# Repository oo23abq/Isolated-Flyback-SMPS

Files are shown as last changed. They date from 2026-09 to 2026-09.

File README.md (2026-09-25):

# Isolated-Flyback-SMPS-Project-
A breakdown of my first independent PCB project, which was the design of a DC-DC  switch-mode power supply (SMPS) in the flyback converter topology.

## Repository Structure

```markdown

```text
├── docs/                                       # General Documentation 
│   └── report.md                               # Lab Test Report
├── gerbers/                                    # Manufacturing Files
│   └── flybackgerbers.zip                      # Gerber and Drill Archives
├── images/                                     # 3D Renders 
│   ├── lt8300flyback_bottom.png                # Bottom Layer 
│   └── lt8300flyback_top.png                   # Top Layer
├── kicad/                                      # KiCAD Project Files 
│   ├── LT8300_Flyback_RevA.kicad_pcb           # PCB Board File
│   ├── LT8300_Flyback_RevA.kicad_sch           # Schematic File
│   └── LT8300flyback_bom.csv                   # Bill of Materials
├── ltspice/                                    # Analogue Simulation 
│   └── waveform.png                            # LTspice Transient Simulation 
├── testing/                                    # Lab Testing
│   ├── oscilloscopeinput.png                   # Input Voltage (P-Coil)
│   ├── oscilloscopeoutput.png                  # Output Voltage (S-Coil)
│   └── testsetup.png                           # Bench Test Setup 
├── LICENSE                                     # License file
└── README.md                                   # Project documentation and summary

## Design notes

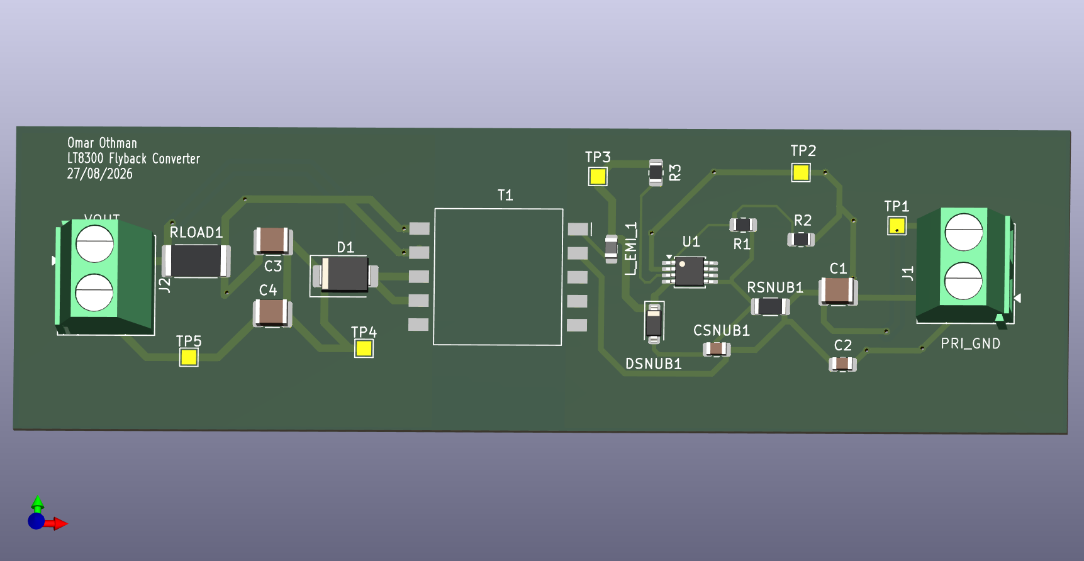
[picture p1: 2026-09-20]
images/lt8300flyback_top.png

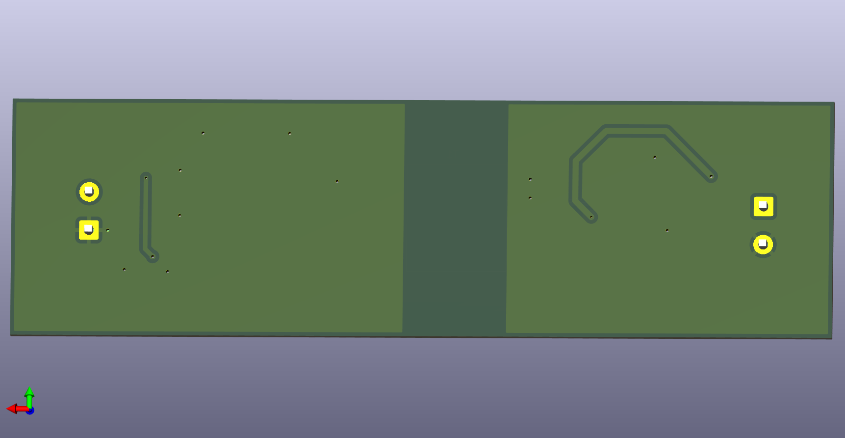
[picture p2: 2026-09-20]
images/lt8300flyback_bottom.png

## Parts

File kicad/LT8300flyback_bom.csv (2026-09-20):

Reference | Qty | Value | DNP | Exclude from BOM | Exclude from Board | Footprint | Datasheet
C1 | 1 | 47u |  |  |  | Capacitor_SMD:C_1210_3225Metric | ~
C2 | 1 | 47n |  |  |  | Capacitor_SMD:C_0805_2012Metric | ~
C3,C4 | 2 | 47µ |  |  |  | Capacitor_SMD:C_1210_3225Metric
CSNUB1 | 1 | 0.001µ |  |  |  | Capacitor_SMD:C_0805_2012Metric
D1 | 1 | MBRS1100 |  |  |  | Diode_SMD:D_SMB
DSNUB1 | 1 | 1N4148 |  |  |  | Diode_SMD:D_SOD-123
J1 | 1 | Input |  |  |  | TerminalBlock_Phoenix:TerminalBlock_Phoenix_MKDS-1,5-2-5.08_1x02_P5.08mm_Horizontal | ~
J2 | 1 | Output |  |  |  | TerminalBlock_Phoenix:TerminalBlock_Phoenix_MKDS-1,5-2-5.08_1x02_P5.08mm_Horizontal | ~
L_EMI_1 | 1 | 5n |  |  |  | Inductor_SMD:L_0805_2012Metric | ~
R1,R3 | 2 | 1M |  |  |  | Resistor_SMD:R_0805_2012Metric
R2 | 1 | 40.2K |  |  |  | Resistor_SMD:R_0805_2012Metric
RLOAD1 | 1 | 16 |  |  |  | Resistor_SMD:R_2512_6332Metric
RSNUB1 | 1 | 10K |  |  |  | Resistor_SMD:R_1206_3216Metric
T1 | 1 | EPQ13_6389_10PINS_750318525 |  |  |  | Transformer_SMD_Wurth:T_Wurth_WE-FLYTI-EPQ13_6389_10PINS | https://www.we-online.com/catalog/datasheet/750318525.pdf?ki
TP1 | 1 | TP_VIN |  |  |  | TestPoint:TestPoint_Pad_1.5x1.5mm | ~
TP2 | 1 | TP_PRI_GND |  |  |  | TestPoint:TestPoint_Pad_1.5x1.5mm | ~
TP3 | 1 | TP_SW |  |  |  | TestPoint:TestPoint_Pad_1.5x1.5mm | ~
TP4 | 1 | TP_VOUT+ |  |  |  | TestPoint:TestPoint_Pad_1.5x1.5mm | ~
TP5 | 1 | TP_VOUT- |  |  |  | TestPoint:TestPoint_Pad_1.5x1.5mm | ~
U1 | 1 | LT8300 |  |  |  | Package_SO:MSOP-8-1EP_3x3mm_P0.65mm_EP1.5x1.8mm

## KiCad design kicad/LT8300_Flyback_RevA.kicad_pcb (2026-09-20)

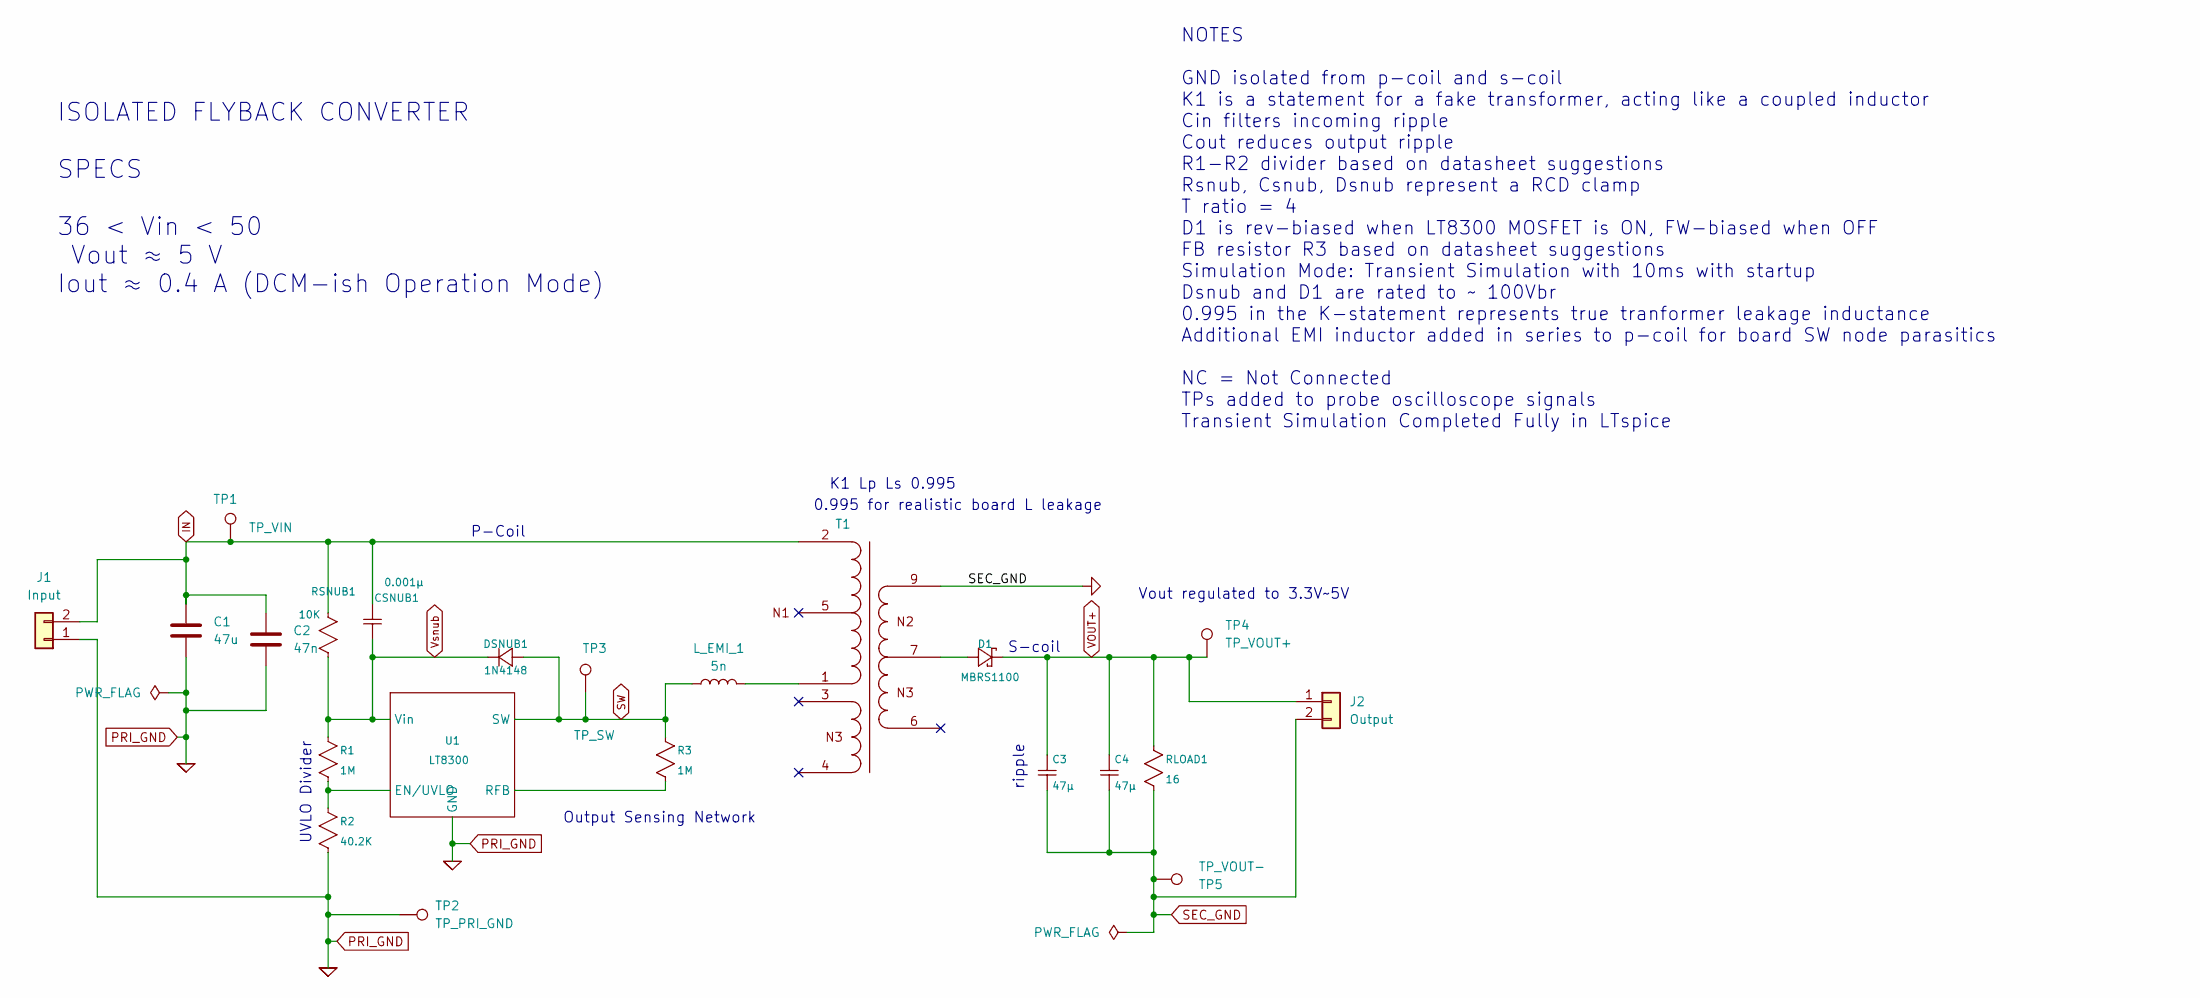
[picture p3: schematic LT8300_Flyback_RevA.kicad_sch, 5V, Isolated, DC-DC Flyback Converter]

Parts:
C1: 47u; C_1210_3225Metric
C2: 47n; C_0805_2012Metric
C3, C4: 47µ; C_1210_3225Metric
CSNUB1: 0.001µ; C_0805_2012Metric
D1: MBRS1100; D_SMB
DSNUB1: 1N4148; D_SOD-123
J1: Input; TerminalBlock_Phoenix_MKDS-1,5-2-5.08_1x02_P5.08mm_Horizont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
J2: Output; TerminalBlock_Phoenix_MKDS-1,5-2-5.08_1x02_P5.08mm_Horizont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
L_EMI_1: 5n; L_0805_2012Metric
R1, R3: 1M; R_0805_2012Metric
R2: 40.2K; R_0805_2012Metric
RLOAD1: 16; R_2512_6332Metric
RSNUB1: 10K; R_1206_3216Metric
T1: EPQ13_6389_10PINS_750318525; T_Wurth_WE-FLYTI-EPQ13_6389_10PINS; Part Number 750318525
TP1: TP_VIN; TestPoint_Pad_1.5x1.5mm
TP2: TP_PRI_GND; TestPoint_Pad_1.5x1.5mm
TP3: TP_SW; TestPoint_Pad_1.5x1.5mm
TP4: TP_VOUT+; TestPoint_Pad_1.5x1.5mm
TP5: TP_VOUT-; TestPoint_Pad_1.5x1.5mm
U1: LT8300; MSOP-8-1EP_3x3mm_P0.65mm_EP1.5x1.8mm

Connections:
IN: C1.1, C2.1, CSNUB1.2, J1.2, RSNUB1.2, T1.2, TP1.1
unnamed: D1.2 (+), T1.7, T1.8
unnamed: L_EMI_1.2, T1.1
unnamed: R1.2, R2.1, U1.1 (EN/UVLO)
unnamed: R3.2, U1.3 (RFB)
PRI_GND: C1.2, C2.2, J1.1, R2.2, TP2.1, U1.2 (GND)
SEC_GND: C3.2, C4.2, J2.2, RLOAD1.2, T1.9, T1.10, TP5.1
SW: DSNUB1.1 (+), L_EMI_1.1, R3.1, TP3.1, U1.4 (SW)
VOUT+: C3.1, C4.1, D1.1 (-), J2.1, RLOAD1.1, TP4.1
Vsnub: CSNUB1.1, DSNUB1.2 (-), R1.1, RSNUB1.1, U1.5 (Vin)

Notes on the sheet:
S-coil
K1 Lp Ls 0.995
UVLO Divider
NOTES GND isolated from p-coil and s-coil K1 is a statement for a fake transformer, acting like a coupled inductor Cin filters incoming ripple Cout reduces output ripple R1-R2 divider based on datasheet suggestions Rsnub, Csnub, Dsnub represent a RCD clamp T ratio = 4 D1 is rev-biased when LT8300 M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
P-Coil
ripple
Vout regulated to 3.3V~5V
ISOLATED FLYBACK CONVERTER SPECS 36 < Vin < 50 Vout ≈ 5 V Iout ≈ 0.4 A (DCM-ish Operation Mode)
0.995 for realistic board L leakage
Output Sensing Network

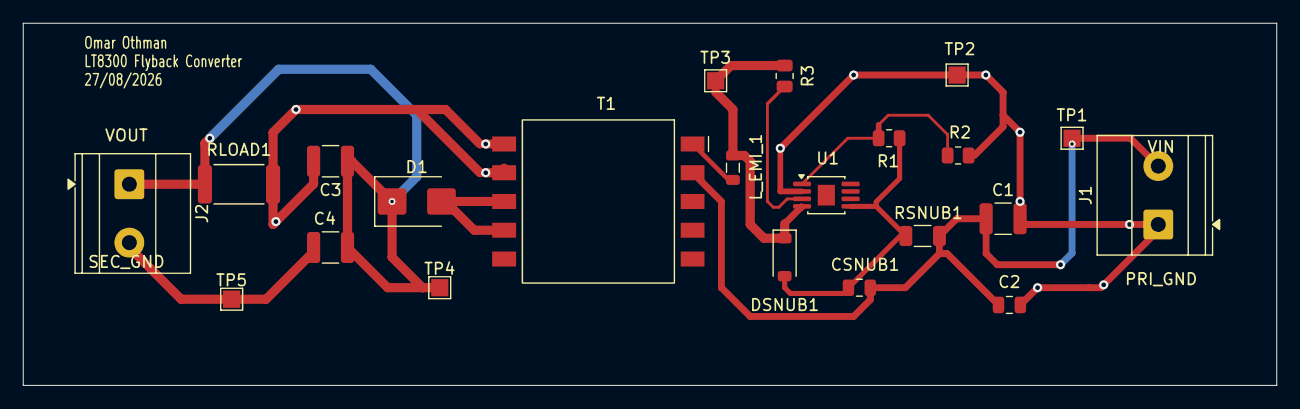
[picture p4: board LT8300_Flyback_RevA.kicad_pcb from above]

Board: 2 copper layers, 109.0 x 31.5 mm, 22 parts (0 on the bottom side), 10 nets.
